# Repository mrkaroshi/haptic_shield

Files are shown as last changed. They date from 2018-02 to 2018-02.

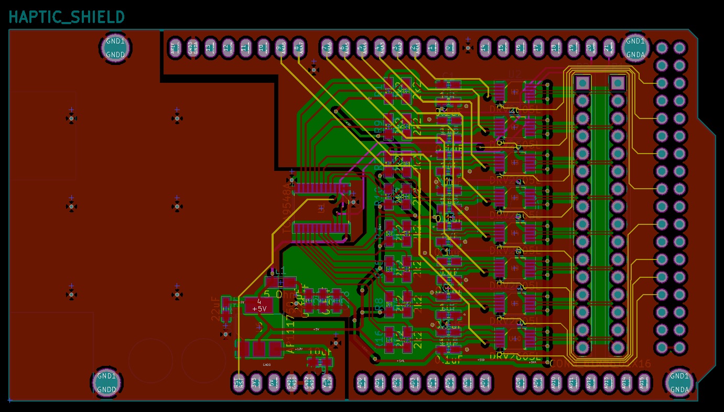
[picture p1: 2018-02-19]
haptic_shield.jpg

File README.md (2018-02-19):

This hardware and software is provided under the MIT License.

Haptic Shield Firmware cheatsheet:

'd' - debug mode, will print out all changes

'eX' - enable a driver, X is the number and they go in order left to right of '8, 4, 2, 1, 128, 64, 32, 16' (don't ask why)

'p' - puts selected driver into playback mode, and it will accept values of voltage level

'rX' - sets the voltage level of a driver output, 128 being the midpoint (highest)

'iX' - puts the selected driver into trigger mode, X is the number code for the waveform you want to set (see the datasheet). If you don't set X it will default to either 16 or the last used.

't' - triggers the enabled driver provided it has been selected with 'eX'

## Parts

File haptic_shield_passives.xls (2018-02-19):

HAPTIC SHIELD PASSIVES
Mouser No | Mfr. No | Manufacturer | Customer No | Description | RoHS | Lifecycle | Order Qty. | Price (EUR) | Ext.: (EUR)
81-BLM18BB050SZ1D | BLM18BB050SZ1D | Murata |  | Ferrite Beads 0603 5ohms 700mA Auto Infotainment | RoHS Compliant | New At Mouser | 4 | € 0,094 | € 0,38
71-CRCW06032K20JNEAH | CRCW06032K20JNEAHP | Vishay |  | Thick Film Resistors - SMD 1/4watt 2.2Kohms 5% High Power AEC-Q200 | RoHS Compliant By Exemption |  | 17 | € 0,103 | € 1,75
581-0603ZD226MAT2A | 0603ZD226MAT2A | AVX |  | Multilayer Ceramic Capacitors MLCC - SMD/SMT 10V 22uF X5R 0603 20% Tol HIGH CV | RoHS Compliant | New Product | 3 | € 0,321 | € 0,96
571-5-826629-0 | 5-826629-0 | TE Connectivity |  | Headers & Wire Housings 50P SINGLE ROW | RoHS Compliant |  | 3 | € 3,45 | € 10,35

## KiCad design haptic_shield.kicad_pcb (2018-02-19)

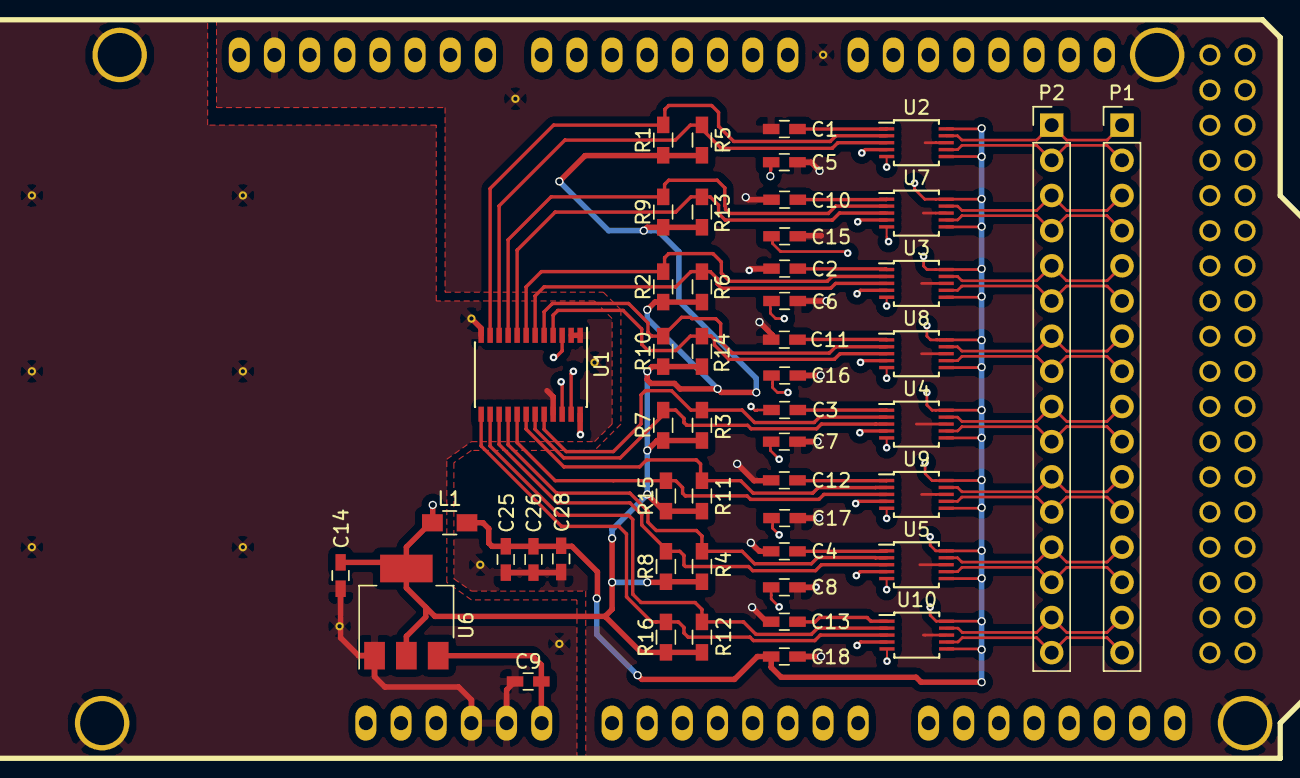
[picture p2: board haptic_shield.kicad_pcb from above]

Board: 4 copper layers, 64 parts (0 on the bottom side), 64 nets.

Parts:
C1, C2, C3, C4, C10, C11, C12, C13: 1uF; C_0603_HandSoldering
C5, C6, C7, C8, C15, C16, C17, C18, C28: 0.1uF; C_0603_HandSoldering
C9: 10uF; C_0603_HandSoldering
C14, C25: 22uF; C_0603_HandSoldering
C26: 0.01uF; C_0603_HandSoldering
L1: 5 Ohm; C_0805_HandSoldering
P1, P2: CONN_01X16; Pin_Header_Straight_1x16_Pitch2.54mm
R1, R2, R3, R4, R5, R6, R7, R8, R9, R10, R11, R12, R13, R14, R15, R16: 2k2; R_0603_HandSoldering
SHIELD1: ARDUINO_MEGA_SHIELD; ARDUINO_MEGA_SHIELD_040pins
U1: TCA9548A; TSSOP-24_4.4x7.8mm_Pitch0.65mm
U2, U3, U4, U5, U7, U8, U9, U10: DRV2605L; TSSOP-10_3x3mm_Pitch0.5mm
U6: AP111750; SOT-223
V: VIA-0.6mm
V#2, V#3, V#4, V#5, V#6, V#7, V#8, V#9, V#10, V#11, V#12, V#13: VIA-0.6mm

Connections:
+5V: C14.1, L1.1, R1.1, R2.1, R3.1, R4.1, R5.1, R6.1, R7.1, R8.1, R9.1, R10.1, R11.1, R12.1, R13.1, R14.1, R15.1, R16.1, U1.24, U6.2, U6.4
+5VA: C5.1, C6.1, C7.1, C8.1, C15.1, C16.1, C17.1, C18.1, C25.1, C26.1, C28.1, L1.2, U2.6, U2.10, U3.6, U3.10, U4.6, U4.10, U5.6, U5.10, U7.6, U7.10, U8.6, U8.10, U9.6, U9.10, U10.6, U10.10
+12V: C9.1, SHIELD1.V_IN, U6.3
ANA1: SHIELD1.2, U2.4
ANA2: SHIELD1.3, U7.4
ANA3: SHIELD1.4, U3.4
ANA4: SHIELD1.5, U8.4
ANA5: SHIELD1.6, U4.4
ANA6: SHIELD1.7, U9.4
ANA7: SHIELD1.8, U5.4
ANA8: SHIELD1.9, U10.4
EN1: SHIELD1.24, U2.5
EN2: SHIELD1.28, U7.5
EN3: SHIELD1.32, U3.5
EN4: SHIELD1.36, U8.5
EN5: SHIELD1.40, U4.5
EN6: SHIELD1.44, U9.5
EN7: SHIELD1.46, U5.5
EN8: SHIELD1.48, U10.5
GNDA: C1.1, C2.1, C3.1, C4.1, C5.2, C6.2, C7.2, C8.2, C10.1, C11.1, C12.1, C13.1, C15.2, C16.2, C17.2, C18.2, C25.2, C26.2, C28.2, SHIELD1.GND1, SHIELD1.GND3, U2.8, U3.8, U4.8, U5.8, U7.8, U8.8, U9.8, U10.8, V#7.1, V#10.1, V#13.1
GNDD: C9.2, C14.2, SHIELD1.GND1, SHIELD1.GND2, SHIELD1.GND4, SHIELD1.GND5, U1.1, U1.2, U1.12, U1.21, U6.1, V.1, V#2.1, V#3.1, V#4.1, V#5.1, V#6.1, V#8.1, V#9.1, V#11.1, V#12.1
MOT1+: P1.2, P2.2, U2.7
MOT1-: P1.1, P2.1, U2.9
MOT2+: P1.4, P2.4, U7.7
MOT2-: P1.3, P2.3, U7.9
MOT3+: P1.6, P2.6, U3.7
MOT3-: P1.5, P2.5, U3.9
MOT4+: P1.8, P2.8, U8.7
MOT4-: P1.7, P2.7, U8.9
MOT5+: P1.10, P2.10, U4.7
MOT5-: P1.9, P2.9, U4.9
MOT6+: P1.12, P2.12, U9.7
MOT6-: P1.11, P2.11, U9.9
MOT7+: P1.14, P2.14, U5.7
MOT7-: P1.13, P2.13, U5.9
MOT8+: P1.16, P2.16, U10.7
MOT8-: P1.15, P2.15, U10.9
unnamed: C1.2, U2.1
unnamed: C2.2, U3.1
unnamed: C3.2, U4.1
unnamed: C4.2, U5.1
unnamed: C10.2, U7.1
unnamed: C11.2, U8.1
unnamed: C12.2, U9.1
unnamed: C13.2, U10.1
RST: SHIELD1.RST, U1.3
SC0: R1.2, U1.11, U2.2
SC1: R9.2, U1.9, U7.2
SC2: R2.2, U1.7, U3.2
SC3: R10.2, U1.5, U8.2
SC4: R3.2, U1.20, U4.2
SC5: R11.2, U1.18, U9.2
SC6: R4.2, U1.16, U5.2
SC7: R12.2, U1.14, U10.2
SCL_MASTER: SHIELD1.21, U1.22
SD0: R5.2, U1.10, U2.3
SD1: R13.2, U1.8, U7.3
SD2: R6.2, U1.6, U3.3
SD3: R14.2, U1.4, U8.3
SD4: R7.2, U1.19, U4.3
SD5: R15.2, U1.17, U9.3
SD6: R8.2, U1.15, U5.3
SD7: R16.2, U1.13, U10.3
SDA_MASTER: SHIELD1.20, U1.23
